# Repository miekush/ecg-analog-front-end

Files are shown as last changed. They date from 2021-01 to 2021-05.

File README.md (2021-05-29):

# ECG_Analog_Front_End
Simple Analog Front End for Electrocardiography using INA126 and OPA2337

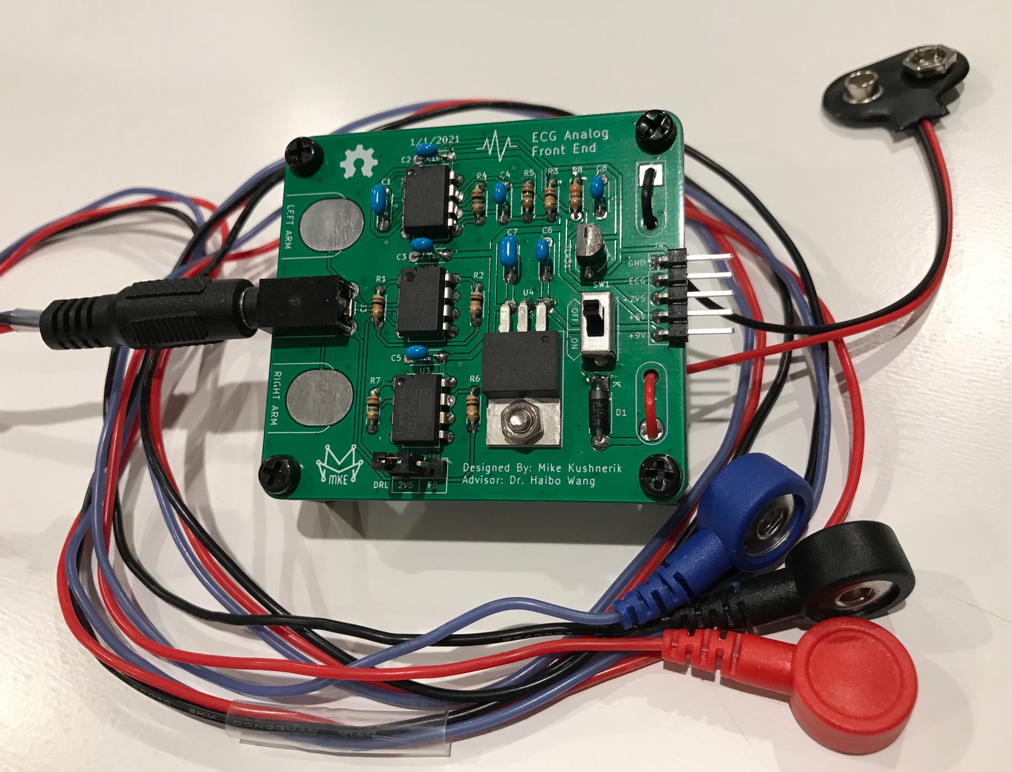
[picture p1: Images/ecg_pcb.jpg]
PCB ISO


# License

MKE supports the open source hardware community by sharing hardware design files freely on GitHub!

Please support MKE by purchasing products on [Tindie](https://www.tindie.com/stores/mkengineering/)!

Designed by Mike Kushnerik for MKEngineering

Licensed under [Creative Commons Attribution-ShareAlike CC BY-SA 3.0](http://creativecommons.org/licenses/by-sa/3.0/)

All text above must be included in any redistribution!

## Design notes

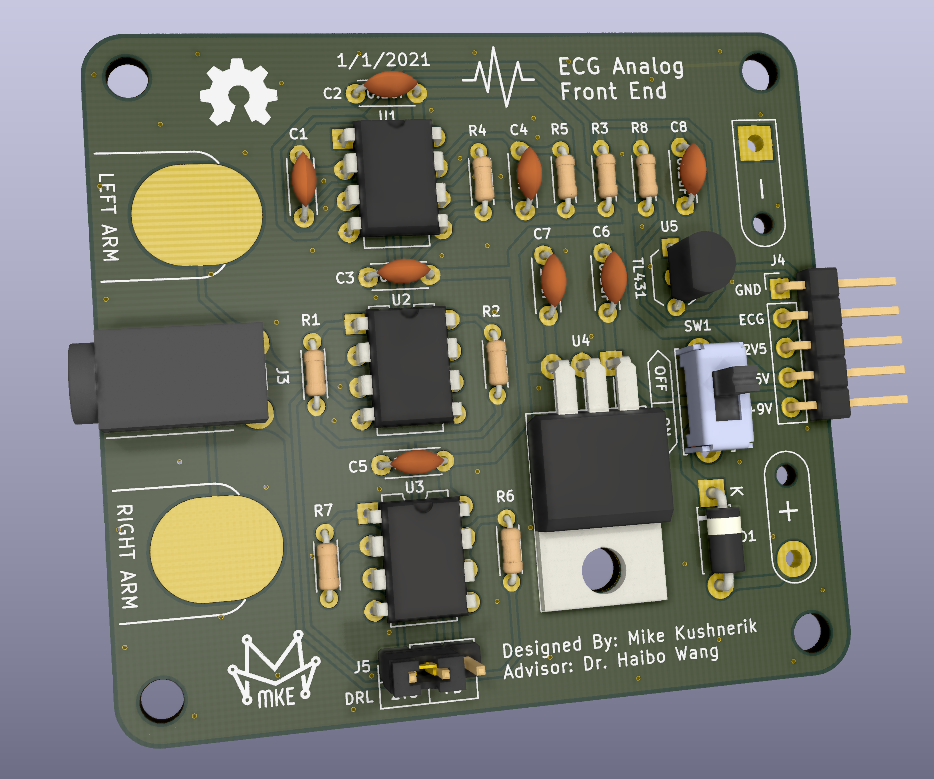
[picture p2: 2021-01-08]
Images/ECG_iso.PNG

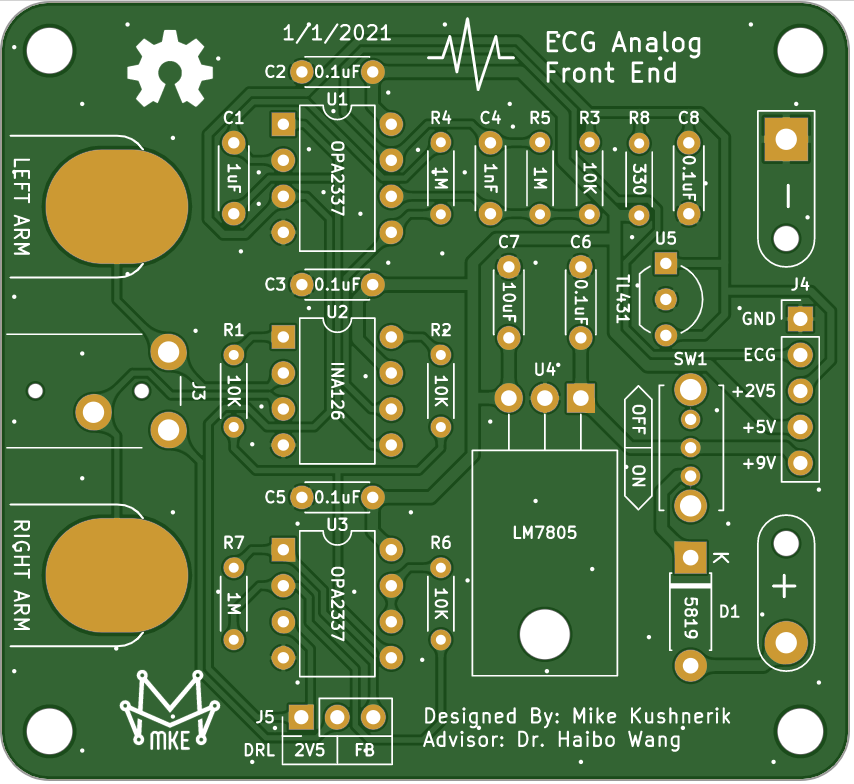
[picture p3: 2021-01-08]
Images/ECG_gerber.PNG

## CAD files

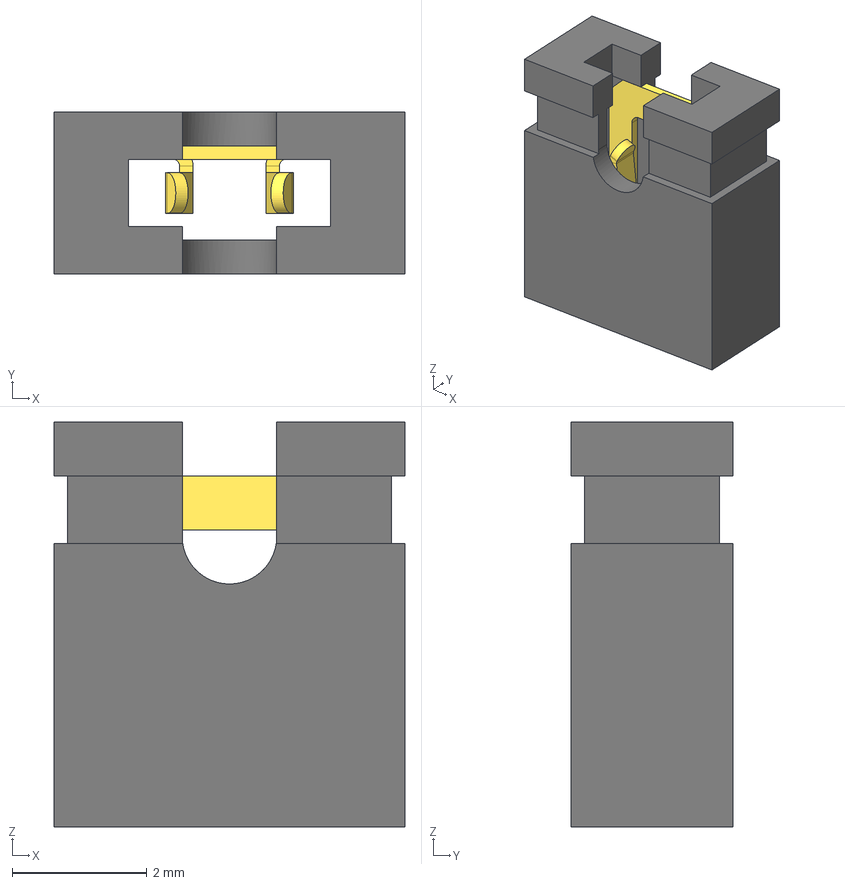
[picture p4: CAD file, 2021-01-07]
3D Models/Jumper.step
5.20 x 2.40 x 6.00 mm

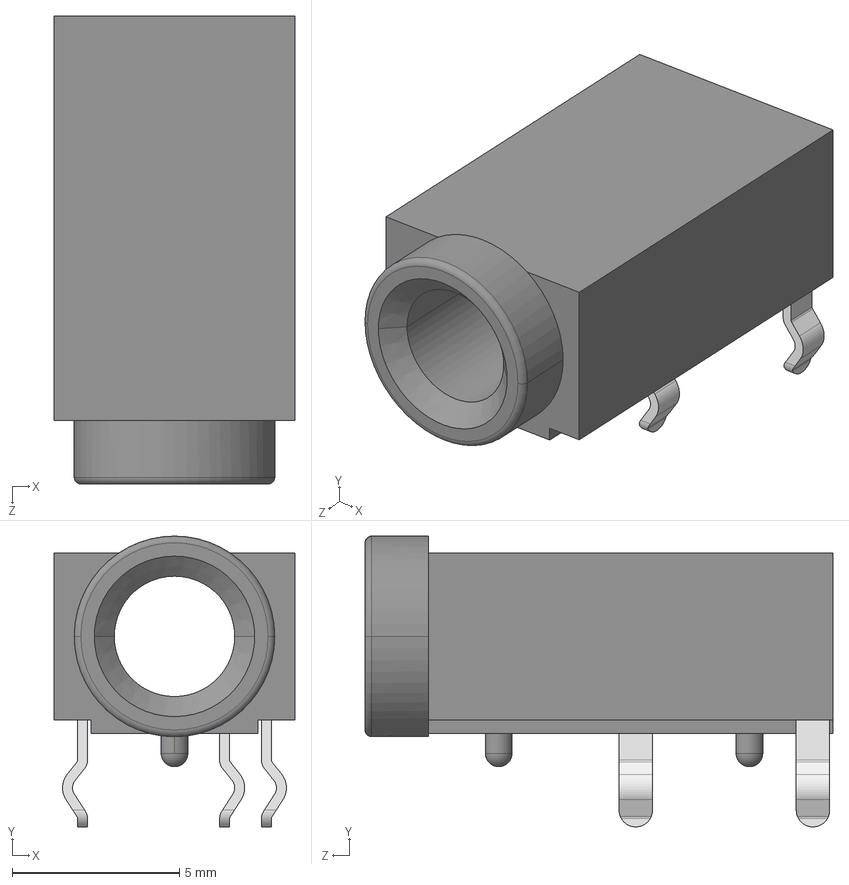
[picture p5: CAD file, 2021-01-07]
3D Models/STX-3000_rD3.STEP
7.20 x 8.70 x 14.0 mm

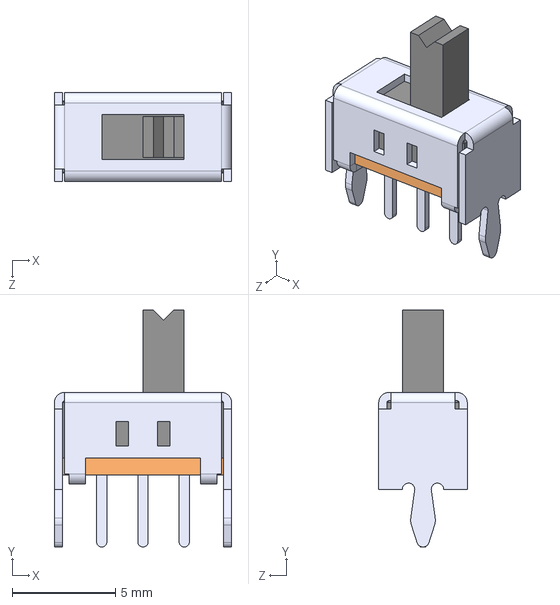
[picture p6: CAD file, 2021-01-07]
3D Models/OS102011MS2QN1--3DModel-STEP-1.STEP
8.60 x 11.5 x 4.30 mm

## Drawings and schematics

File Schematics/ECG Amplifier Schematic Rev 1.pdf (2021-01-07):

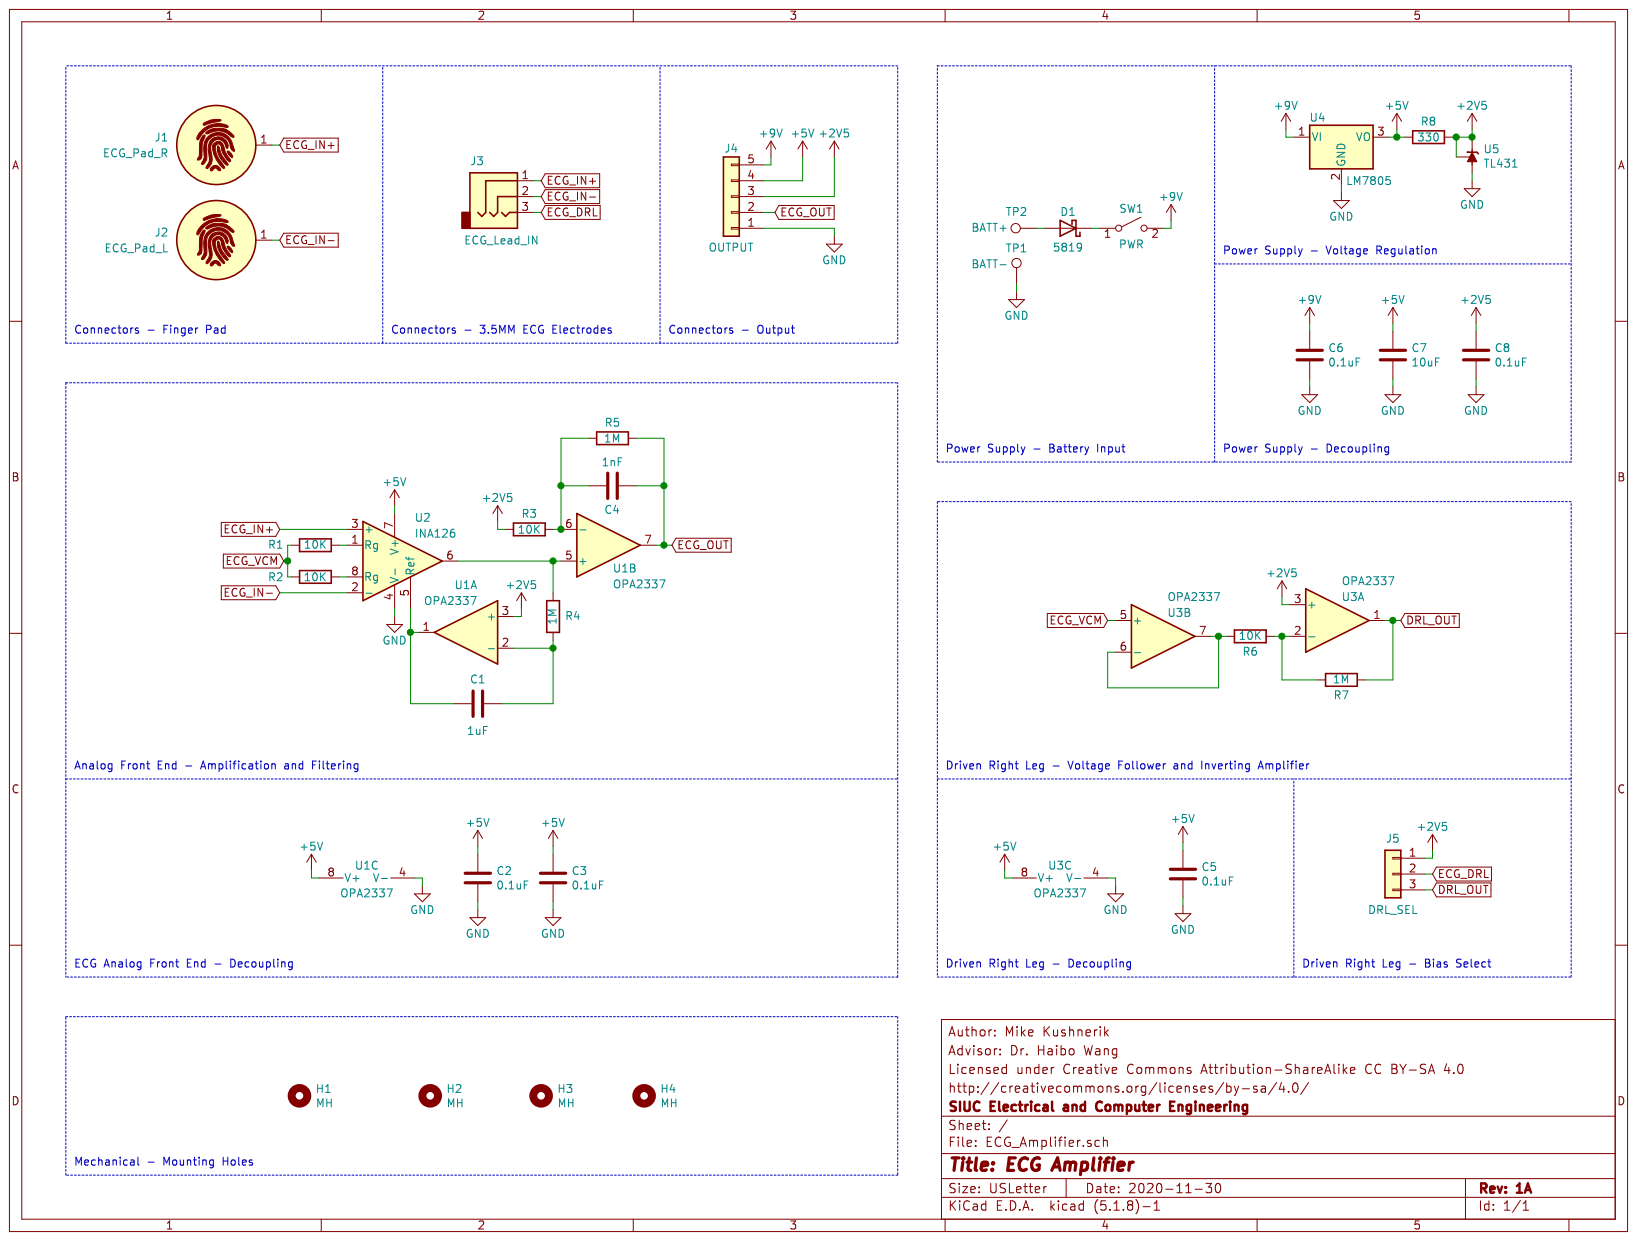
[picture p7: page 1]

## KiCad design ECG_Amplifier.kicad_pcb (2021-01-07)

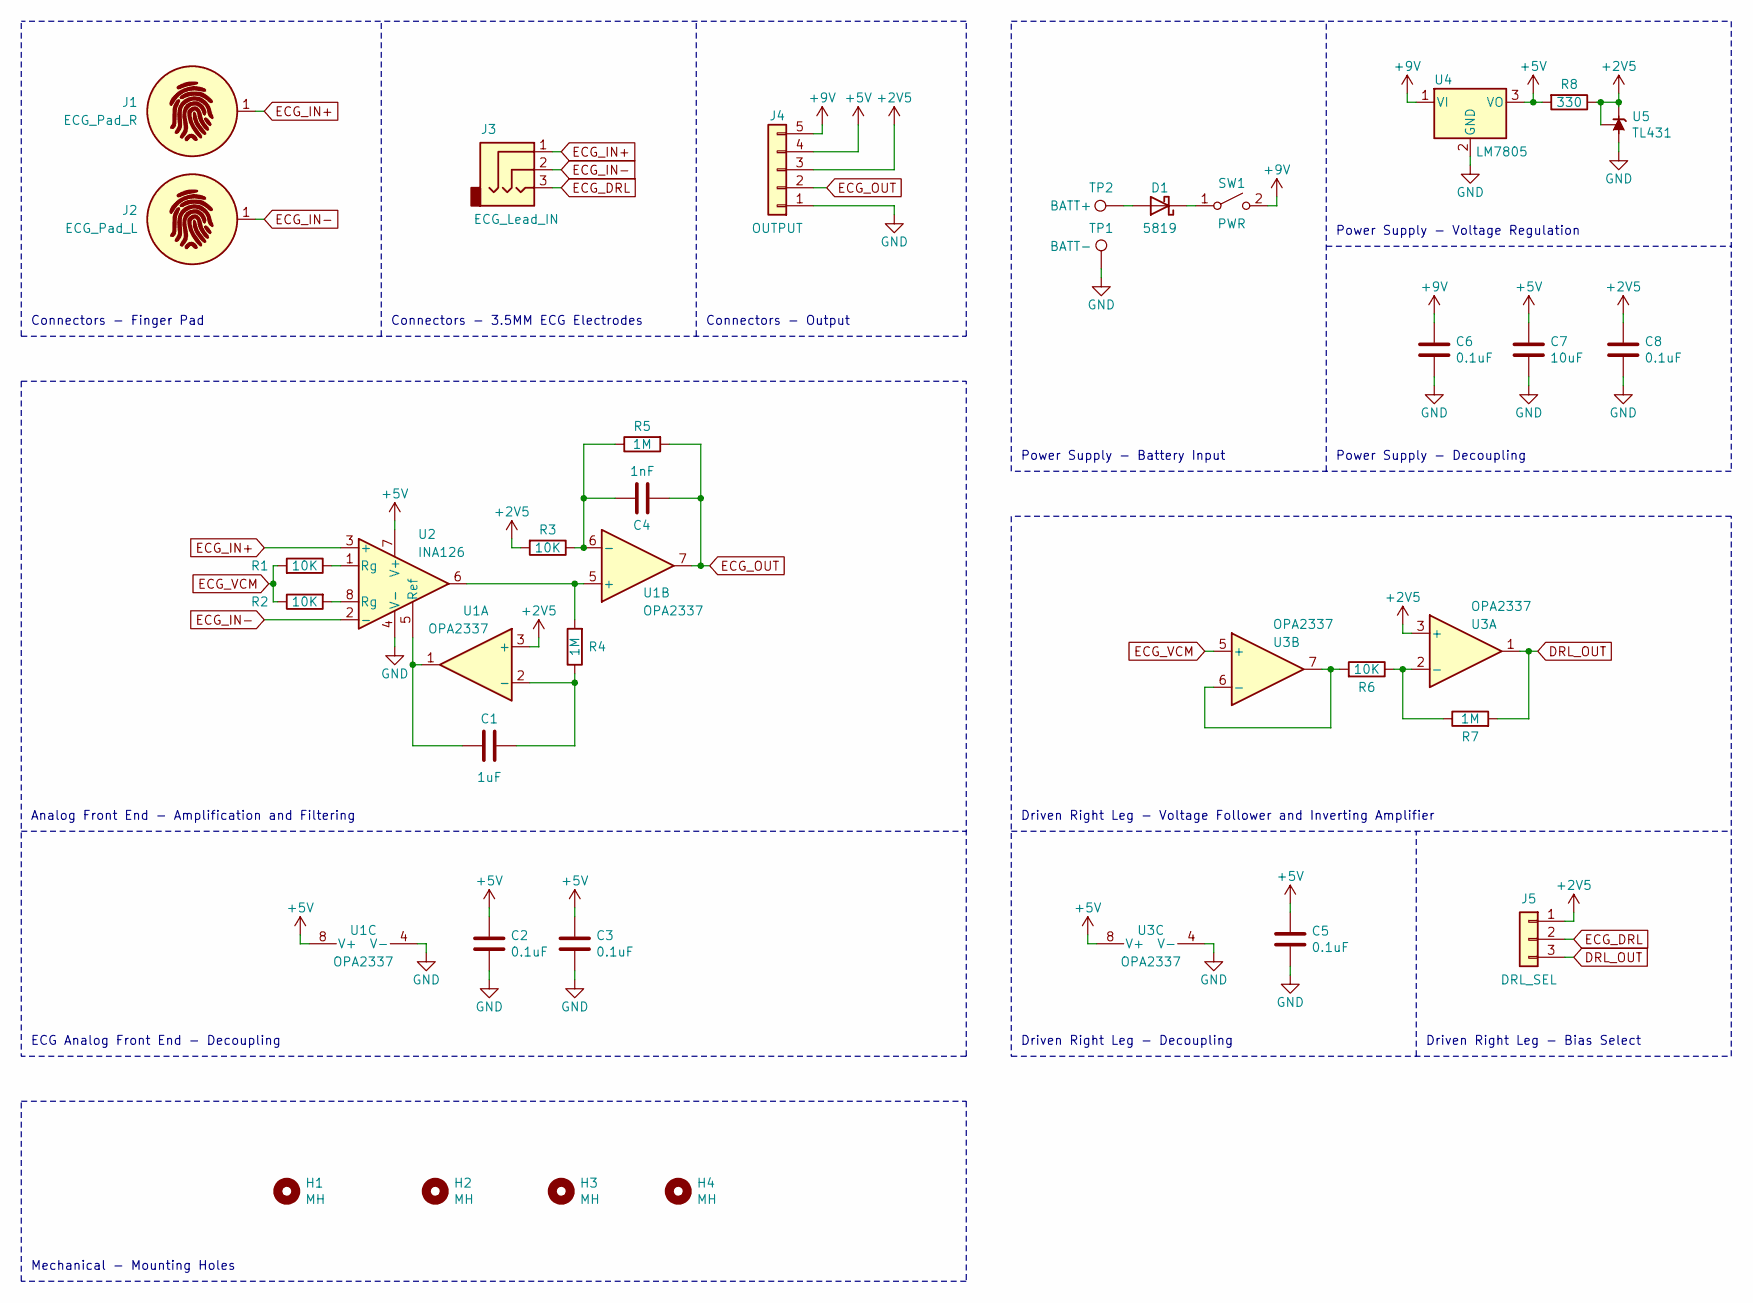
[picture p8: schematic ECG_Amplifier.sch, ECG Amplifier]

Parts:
C1: 1uF; C_Disc_D4.3mm_W1.9mm_P5.00mm
C2, C3, C5, C6, C8: 0.1uF; C_Disc_D4.3mm_W1.9mm_P5.00mm
C4: 1nF; C_Disc_D4.3mm_W1.9mm_P5.00mm
C7: 10uF; C_Disc_D4.3mm_W1.9mm_P5.00mm
D1: 5819; D_DO-41_SOD81_P7.62mm_Horizontal
H1, H2, H3, H4: MH; MountingHole_3.2mm_M3
J1: ECG_Pad_R; ECG_Electrode_Pad
J2: ECG_Pad_L; ECG_Electrode_Pad
J3: ECG_Lead_IN; STX-3000
J4: OUTPUT; PinHeader_1x05_P2.54mm_Vertical
J5: DRL_SEL; PinHeader_1x03_P2.54mm_Vertical
R1, R2, R3, R6: 10K; R_Axial_DIN0204_L3.6mm_D1.6mm_P5.08mm_Horizontal
R4, R5, R7: 1M; R_Axial_DIN0204_L3.6mm_D1.6mm_P5.08mm_Horizontal
R8: 330; R_Axial_DIN0204_L3.6mm_D1.6mm_P5.08mm_Horizontal
SW1: PWR; OS102011MS2QN1
TP1: BATT-; WIRE_SR_R
TP2: BATT+; WIRE_SR_C
U1, U3: OPA2337; DIP-8_W7.62mm
U2: INA126; DIP-8_W7.62mm
U4: LM7805; TO-220-3_Horizontal_TabDown
U5: TL431; TO-92_Inline_Wide

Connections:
+2V5: C8.1, J4.3, J5.1, R3.2, R8.1, U1.3 (+), U3.3 (+), U5.1 (REF), U5.3 (K)
+5V: C2.1, C3.1, C5.1, C7.1, J4.4, R8.2, U1.8 (V+), U2.7 (V+), U3.8 (V+), U4.3 (VO)
+9V: C6.1, J4.5, SW1.2 (B), U4.1 (VI)
DRL_OUT: J5.3, R7.2, U3.1
ECG_DRL: J3.3, J5.2
ECG_IN+: J1.1, J3.1, U2.3 (+)
ECG_IN-: J2.1, J3.2, U2.2 (-)
ECG_OUT: C4.2, J4.2, R5.2, U1.7
ECG_VCM: R1.2, R2.1, U3.5 (+)
GND: C2.2, C3.2, C5.2, C6.2, C7.2, C8.2, J4.1, TP1.1, U1.4 (V-), U2.4 (V-), U3.4 (V-), U4.2 (GND), U5.2 (A)
unnamed: C1.1, R4.1, U1.2 (-)
unnamed: C1.2, U1.1, U2.5 (Ref)
unnamed: C4.1, R3.1, R5.1, U1.6 (-)
unnamed: D1.1 (K), SW1.1 (A)
unnamed: D1.2 (A), TP2.1
unnamed: R1.1, U2.1 (Rg)
unnamed: R2.2, U2.8 (Rg)
unnamed: R4.2, U1.5 (+), U2.6
unnamed: R6.1, R7.1, U3.2 (-)
unnamed: R6.2, U3.6 (-), U3.7

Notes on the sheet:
Connectors - Finger Pad
Driven Right Leg - Decoupling
Power Supply - Battery Input
Connectors - 3.5MM ECG Electrodes
Connectors - Output
Power Supply - Voltage Regulation
Power Supply - Decoupling
Mechanical - Mounting Holes
Driven Right Leg - Voltage Follower and Inverting Amplifier
Driven Right Leg - Bias Select
Analog Front End - Amplification and Filtering
ECG Analog Front End - Decoupling

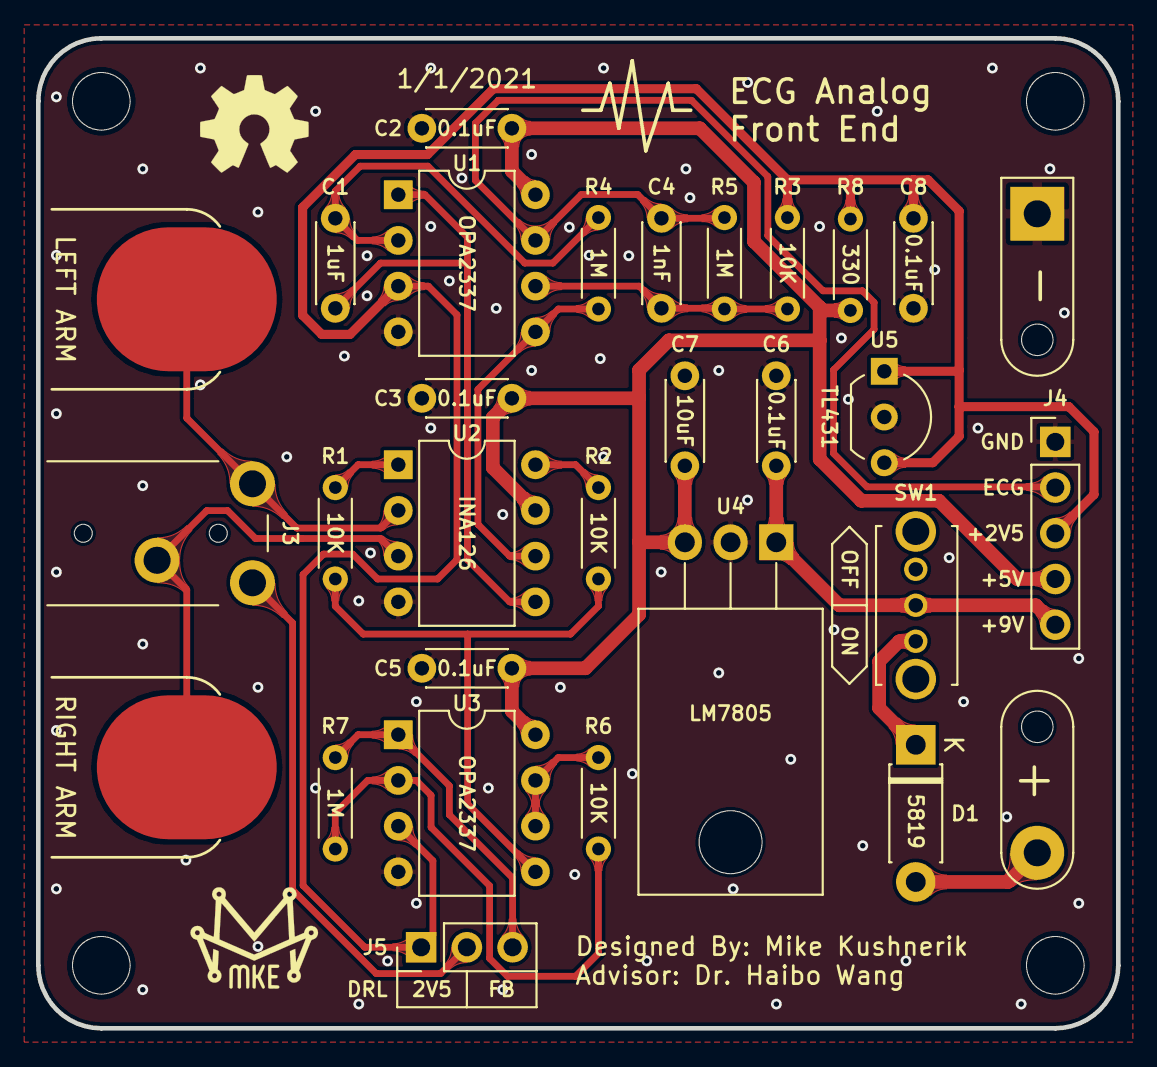
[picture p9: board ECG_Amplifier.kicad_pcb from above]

Board: 2 copper layers, 60.0 x 55.0 mm, 34 parts (0 on the bottom side), 20 nets.

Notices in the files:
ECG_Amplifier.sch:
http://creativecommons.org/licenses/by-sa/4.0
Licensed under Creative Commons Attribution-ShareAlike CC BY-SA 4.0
